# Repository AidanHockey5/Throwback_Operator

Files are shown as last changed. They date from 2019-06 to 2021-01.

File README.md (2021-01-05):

# THROWBACK OPERATOR
OPL3 VGM player powered by STM32

This project is a hardware video game music (VGM) player that uses a genuine YMF262 (OPL3) sound chip and its accompanying YAC512 DAC.
There is no emulation here. This is the real chip.

Included in this repository is the complete schematic, firmware source, and KiCAD board files. Feel free to make your own board, but please don't resell them :)

If you would like to purchase an official complete Throwback Operator board, you can order one from me here: https://www.aidanlawrence.com/product/throwback-operator/

# Information About the Main Sound Chips and VGM

The YMF262, also known as the Operator Type L3 (OPL3), is an 18-channel FM sound chip that was commonly found inside of personal computers in the mid to late 1990's.
Most notably, the OPL3 was found on the Sound Blaster Pro 2 and the Sound Blaster 16.
The OPL3 is backwards compatible with the OPL2 (YM3812). The OPL2 is backwards compatible with the original OPL (YM3526).
This means that the Throwback Operator is capable of playing back OPL3, OPL2, and OPL tracks. The OPL2 was found on the original Adlib and Sound Blaster cards.
The OPL was usually found within arcade machines.

The clock signal for the YMF262 is dynamically generated from the microcontroller. The timers on this particular board only have 16-bit resolution, so VGMs with exotic frequencies may not sound perfectly in tune. Standard clock OPL2 and OPL3 VGMs will often sound just fine though.

VGM stands for Video Game Music, and it is a 44.1KHz logging format that stores real sound chip register information. My player will parse these files and send the data to the appropriate chips. You can learn more about the VGM file format here: http://www.smspower.org/Music/VGMFileFormat

http://www.smspower.org/uploads/Music/vgmspec170.txt?sid=58da937e68300c059412b536d4db2ca0

# Schematic
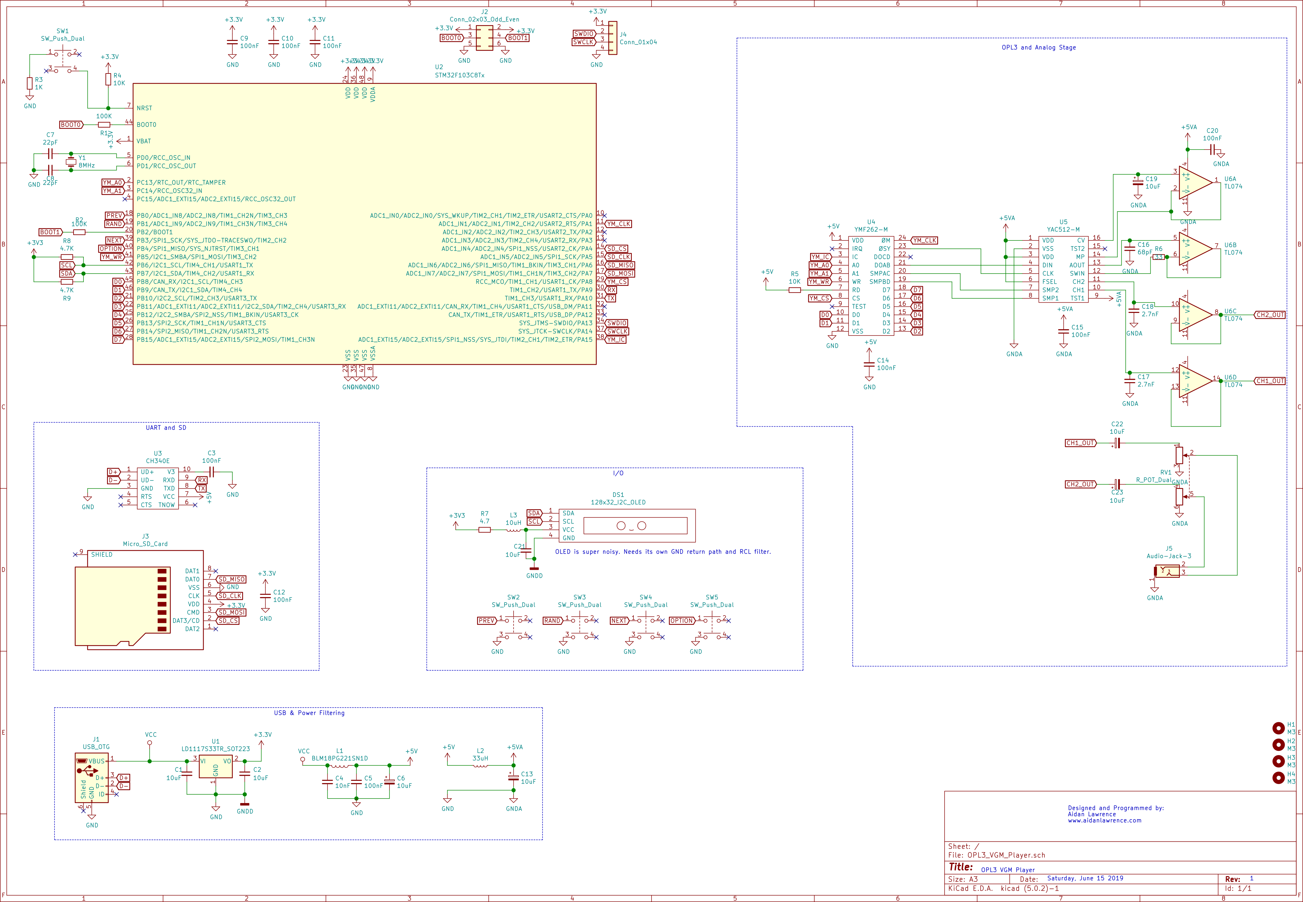
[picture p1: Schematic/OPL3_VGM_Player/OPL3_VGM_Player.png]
Schematic


# SD Card Information

The Throwback Operator accepts MicroSD cards formatted as FAT32. Your SD card must only contain uncompressed .vgm files. VGZ FILES WILL NOT WORK! You may download .vgz files and use 7zip to extract the uncompressed file out of them. Vgm files on the SD card do not need to have the .vgm extension. As long as they contain valid, uncompressed vgm data, they will be read by the program regardless of their name. You can find VGM files by Googling "myGameName VGM," or by checking out sites like http://vgmrips.net/packs/

# Control Over Serial
You can use a serial connection to control playback features. The commands are as follows:

Command | Result
------------ | -------------
\+ | Next Track
\- | Previous Track
\* | Random Track
\/ | Toggle Shuffle Mode
\. | Toggle Song Looping
r: | Request song
? | What song is playing?
\! | Toggle the OLED display

A song request is formatted as follows: ```r:mySongFile.vgm```
Once a song request is sent through the serial console, an attempt will be made to open that song file. The file must exist on the SD card, and spelling/capitalization must be correct.
Need an easy-to-use serial console? [I've made one here.](https://github.com/AidanHockey5/OpenArduinoSerialConsole)

# Programming the Microcontroller

The on-board microcontroller is a STM32F103C8T6, the same microcontroller found on the popular "blue pill" development boards. 
Therefore, programming the Throwback Operator boards is fairly similar.
The firmware was built with Visual Studio Code with the PlatformIO extension installed.

Programming over Serial:
* Connect your Throwback Operator board to your computers USB port.
* Ensure that you have the CH340 driver installed. Windows 10 should have this automatically, otherwise, [grab the driver here](https://sparks.gogo.co.nz/ch340.html)
* Ensure nothing else is currently connected to your board over serial.
* On the top of the board, you will see two black jumpers. By default, these jumpers are both in the "Down" position (middle pin and bottom pin jumped).
* Remove the left jumper and reattach it to the "Up" position (middle pin and top pin jumped).
* Press the RESET button on the Throwback Operator board

* You can either program the device with the flashing tool linked below, or from the source code.

[DOWNLOAD THE FLASHING TOOL HERE](https://www.aidanlawrence.com/tools/ee/tbo/Megaflasher_Throwback_Operator.zip)

* Windows users are reccomended to run the pre-compiled "Flash.exe" file.
  All other operating system users must run the Flash.py file. 
  Dependancies and instructions are listed in the Readme file.
* After successfully running the flashing tool, you are done and don't need to continue with the following instructions.

If you plan to build from the source code instead:
* In VS Code (or whatever your IDE of choice is), navigate to the `platformio.ini` and ensure the upload protocol is set to `serial`
* Hit the upload button (Arrow icon in the bottom bar of VS code)
* Once your code is uploaded, replace the left jumper to its original "Down" position 

# Troubleshooting

Occasionally, when the player is first plugged in, it will hang or get caught in a boot-loop. Plugging in a USB cable gives breif moments of unstable power when the contacts inside of the connector are jostling against eachother which may place the SD card in an unknown state. Simply disconnect and reconnect the USB cable if you are caught in a bootloop.

This player is for OPL-family VGMs only. That means you can play any VGM file that contains data for the YM3526 (OPL), YM3812 (OPL2) or the YMF262 (OPL3).

Ensure that your VGM files are uncompressed. VGZ files will not work. Simply use 7zip on VGM files to extract the VGM files within.

Make sure your SD card is formatted to FAT32 and only contains VGM files. Folders are not supported.

# Looking for an Enclosure for your Player?

Voodle has contributed a 3D-printable enclosure for the Throwback Operator!
https://www.thingiverse.com/thing:4577831

Thanks, Voodle!

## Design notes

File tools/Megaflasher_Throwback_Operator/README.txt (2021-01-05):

NO DEPENDANCIES OR PYTHON INSTALL REQUIRED FOR WINDOWS EXE

PYTHON DEPENDANCIES:
Python 3.0+
pyserial
requests

Enter the following commands:

pip install pyserial
pip install requests

Run:
python3 Flash.py

----------------------------------------------

Instructions for use:

On the THROWBACK OPERATOR DEVICE: Move the left jumper pin at the top of the board to the "UP" position.
It should look like this:
https://www.aidanlawrence.com/wp-content/uploads/2021/01/tbojumper-scaled.jpg

Plug-in your THROWBACK OPERATOR to your computer via USB.

Press the RESET BUTTON.

Run the Flash.exe program OR run Flash.py with Python.

Select the COM port of the THROWBACK OPERATOR.

If everything is correct, your system should automatically download the firmware file and flash.

After flashing, replace the jumper's position back to DOWN.

----------------------------------------------

EXE Built with pyinstaller
pyinstaller --onefile Flash.py

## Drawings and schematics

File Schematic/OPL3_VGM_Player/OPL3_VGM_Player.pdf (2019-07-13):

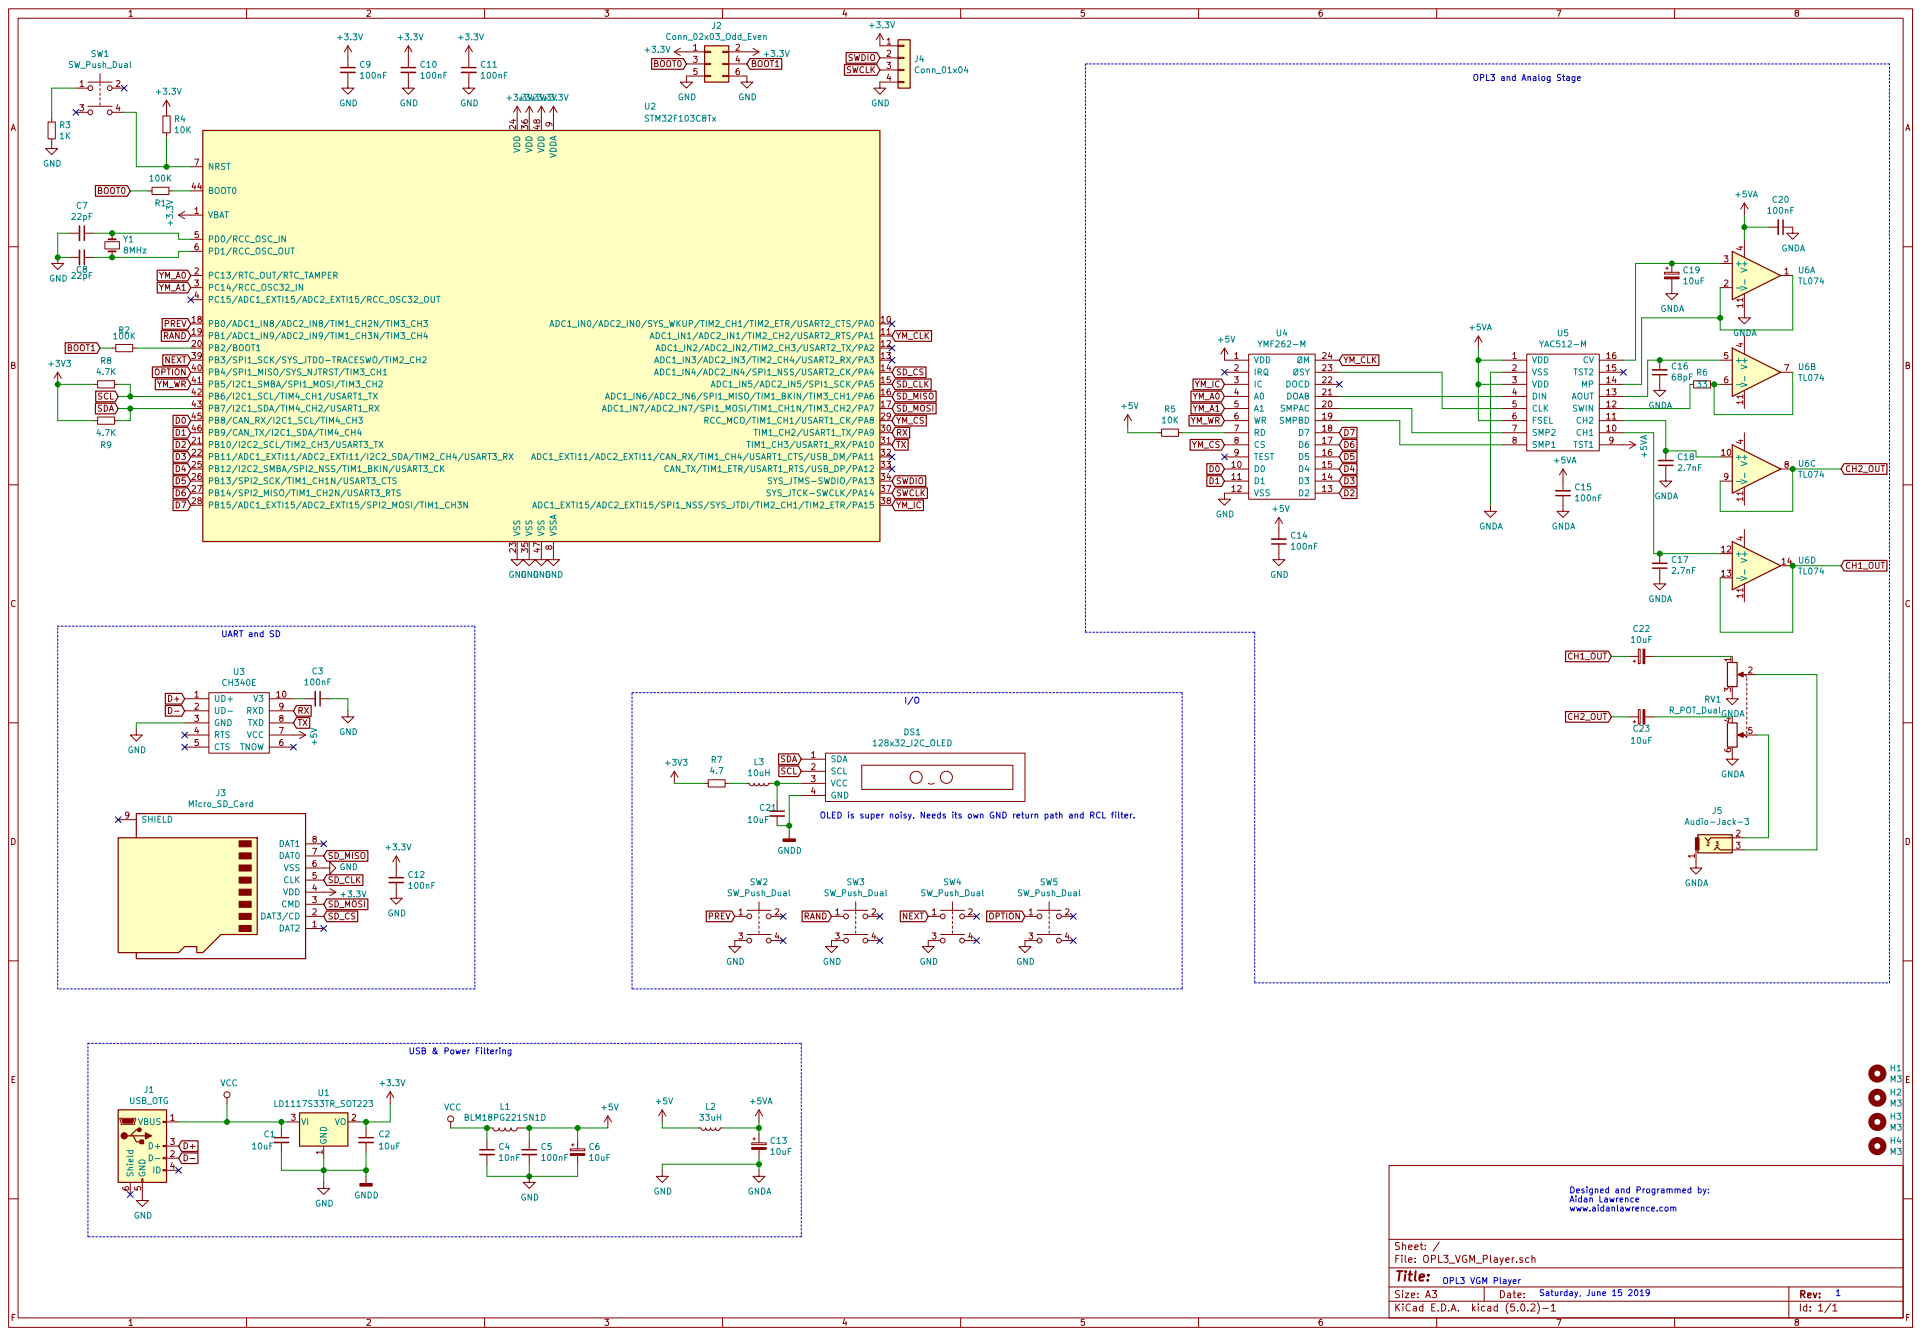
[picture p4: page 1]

9 VSS 23 VSS 35 VSS 47 VSSA

USB & Power Filtering UART and SD

Designed and Programmed by: Aidan Lawrence www.aidanlawrence.com

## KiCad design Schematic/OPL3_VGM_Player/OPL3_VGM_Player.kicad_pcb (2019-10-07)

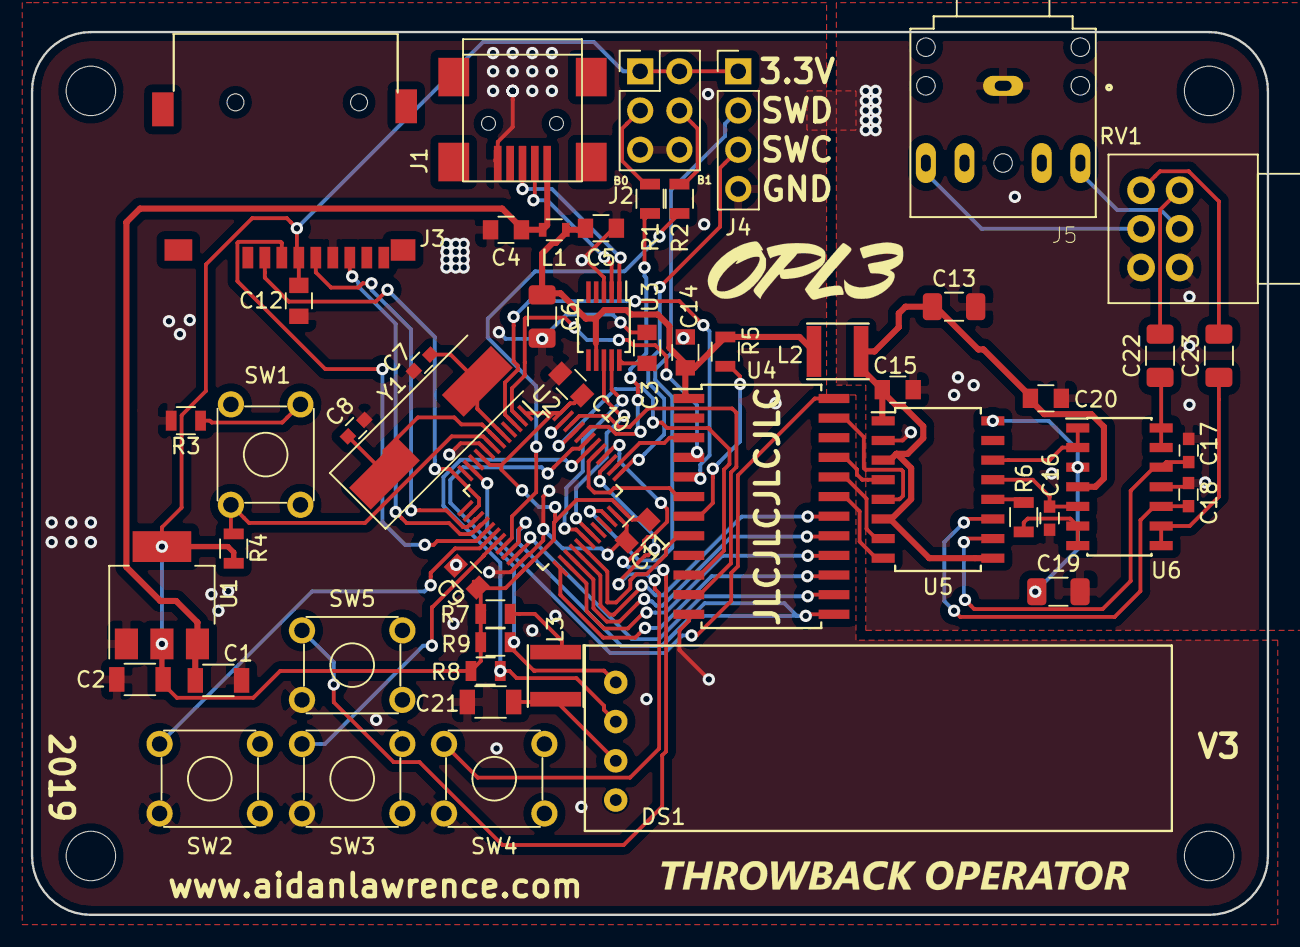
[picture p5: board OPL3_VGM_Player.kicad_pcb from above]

Board: 2 copper layers, 80.0 x 57.2 mm, 58 parts (0 on the bottom side), 64 nets.

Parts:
C1, C2, C21: 10uF; C_1206
C3, C5, C9, C10, C11, C12, C14, C15, C20: 100nF; C_0805
C4: 10nF; C_0805
C6, C13, C19, C22, C23: 10uF; C_1206_3216Metric
C7, C8: 22pF; C_0603
C16: 68pF; C_0603
C17, C18: 2.7nF; C_0603
DS1: 128x32_I2C_OLED; 128x32_OLED_I2C_Module
H1, H2, H3, H4: M3; MountingHole_3.2mm_M3
J1: USB_OTG; USB_Mini-B
J2: Conn_02x03_Odd_Even; Pin_Header_Straight_2x03_Pitch2.54mm
J3: Micro_SD_Card; SOFNG_TF_15x15_PUSH_PUSH
J4: Conn_01x04; Pin_Header_Straight_1x04_Pitch2.54mm
J5: Audio-Jack-3; Boom Precision Elec PJ-307C
L1: BLM18PG221SN1D; L_0603
L2: 33uH; L_4x4
L3: 10uH; L_4x4
R1, R2: 100K; R_0805
R3: 1K; R_0805
R4, R5: 10K; R_0805
R6: 33; R_0805
R7: 4.7; R_0805
R8, R9: 4.7K; R_0805
RV1: R_POT_Dual; Potentiometer_Alps_RK097_Double_Vertical
SW1, SW2, SW3, SW4, SW5: SW_Push_Dual; SW_TH_Tactile_Omron_B3F-10xx
U1: LD1117S33TR_SOT223; SOT-223-3_TabPin2
U2: STM32F103C8Tx; LQFP-48_7x7mm_Pitch0.5mm
U3: CH340E; MSOP-10_3x3mm_Pitch0.5mm
U4: YMF262-M; SOIC-24W_7.5x15.4mm_Pitch1.27mm
U5: YAC512-M; SOIC-16W_5.3x10.2mm_Pitch1.27mm
U6: TL074; SOIC-14_3.9x8.7mm_Pitch1.27mm
Y1: 8MHz; Crystal_SMD_HC49-SD

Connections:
+3V3: C2.1, C9.1, C10.1, C11.1, C12.1, J2.1, J2.2, J3.4, J4.1, R4.1, R7.2, R8.2, R9.2, U1.2, U2.1, U2.9, U2.24, U2.36, U2.48
+5V: C5.1, C6.1, C14.2, L1.1, L2.2, R5.2, U3.7, U4.1
+5VA: C13.1, C15.2, C20.2, L2.1, U5.1, U5.3, U5.6, U5.9, U6.4
BOOT0: J2.3, R1.2
BOOT1: J2.4, R2.2
CH1_OUT: C22.1, U6.13, U6.14
CH2_OUT: C23.1, U6.8, U6.9
D0: U2.45, U4.10
D1: U2.46, U4.11
D2: U2.21, U4.13
D3: U2.22, U4.14
D4: U2.25, U4.15
D5: U2.26, U4.16
D6: U2.27, U4.17
D7: U2.28, U4.18
D+: J1.3, U3.1
D-: J1.2, U3.2
GND: C1.2, C2.2, C3.1, C4.2, C5.2, C6.2, C7.2, C8.2, C9.2, C10.2, C11.2, C12.2, C13.2, C14.1, C15.1, C16.1, C17.1, C18.1, C19.2, C20.1, C21.2, DS1.4, J1.5, J2.5, J2.6, J3.6, J4.4, J5.1, R3.2, RV1.3, RV1.6, SW2.3, SW3.3, SW4.3, SW5.3, U1.1, U2.8, U2.23, U2.35, U2.47, U3.3, U4.12, U5.2
NEXT: SW4.1, U2.39
unnamed: C3.2, U3.10
unnamed: C7.1, U2.5, Y1.2
unnamed: C8.1, U2.6, Y1.1
unnamed: C16.2, U5.13, U6.5
unnamed: C17.2, U5.10, U6.12
unnamed: C18.2, U5.11, U6.10
unnamed: C19.1, U5.16, U6.3
unnamed: C21.1, DS1.3, L3.1
unnamed: C22.2, RV1.1
unnamed: C23.2, RV1.4
unnamed: J5.2, RV1.5
unnamed: J5.3, RV1.2
unnamed: L3.2, R7.1
unnamed: R1.1, U2.44
unnamed: R2.1, U2.20
unnamed: R3.1, SW1.1
unnamed: R4.2, SW1.4, U2.7
unnamed: R5.1, U4.7
unnamed: R6.1, U6.6, U6.7
unnamed: R6.2, U5.12
unnamed: U4.19, U5.8
unnamed: U4.20, U5.7
unnamed: U4.21, U5.4
unnamed: U4.23, U5.5
unnamed: U5.14, U6.1, U6.2
OPTION: SW5.1, U2.40
PREV: SW2.1, U2.18
RAND: SW3.1, U2.19
RX: U2.30, U3.9
SCL: DS1.2, R8.1, U2.42
SDA: DS1.1, R9.1, U2.43
SD_CLK: J3.5, U2.15
SD_CS: J3.2, U2.14
SD_MISO: J3.7, U2.16
SD_MOSI: J3.3, U2.17
SWCLK: J4.3, U2.37
SWDIO: J4.2, U2.34
TX: U2.31, U3.8
VCC: C1.1, C4.1, J1.1, L1.2, U1.3
YM_A0: U2.2, U4.4
YM_A1: U2.3, U4.5
YM_CLK: U2.11, U4.24
YM_CS: U2.29, U4.8
YM_IC: U2.38, U4.3
YM_WR: U2.41, U4.6

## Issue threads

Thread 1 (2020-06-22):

Timing/tempo issues on some VGMs

tomas, 2020-06-22:
I just tried listening to [this soundtrack](https://vgmrips.net/packs/pack/miwaku-no-chousho-pc-9801) from VGMRips, but unfortunately most of the songs seem to be "off" in terms of tempo or timing.

Is this what you refer to about "exotic frequencies" in the readme? Any way this can be fixed?

AidanHockey5, 2020-08-07:
Hello @tomas

Sorry for the late reply. I didn't see this issue!

So I've had issues with that specific VGM pack since day one. I'm not sure what's wrong with the Miwaku no Chousho pack, but I've always run into those same tempo issues on the first loop of some of the tracks. I've doubled-checked the starting addresses on the VGM parser pointer, and they're dead-on, so nothing is wrong with how the file is being parsed.
What's odd is that after the loop point, the track sounds fine, which suggests I might have a buffer issue, but I gave everything a look, and the values all seem to match the VGM file just fine.
There is a note on the VGM pack about "excessive vibrato" due to some conversion between OPN and OPL3, but I don't think that would be an issue. The OPL3 is simply executing the exact commands it receives from the VGM file, so I don't think I'm able to fix this, sadly. May just be a case of a bad VGM capture where software players don't have much of an issue with it, but the real hardware does. I could be wrong though, but since no other tracks behave like this, I'm lead to believe that it's a problem with the VGM files in that pack.

Fortunately, this seems to be the only VGM pack with an issue like this. If I'm missing something, I'd love to be proved wrong! It would be great to get this VGM pack working properly.

As for "exotic frequencies," that simply refers to OPL1/OPL2/OPL3 VGMs setting their chips to run at frequencies that aren't the standard colorburst derivatives. A little bit of math is required to compensate for unusual chip clock speeds, and since the STM32 on-board only has a 16-bit timer, sometimes the resulting clock outputs aren't precisely what the VGM calls for, as the timer resolution is too low. TL;DR, not the issue you're running into :P

AidanHockey5, 2021-01-31:
Finally fixed with the latest firmware's new VGM engine!
https://github.com/AidanHockey5/Throwback_Operator/releases/tag/2.0

#2

Closed 2021-01-31.

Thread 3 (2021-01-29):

Tl074 is marginal at 5V

prosper00, 2021-01-29:
I built up your circuit out of parts i had on hand, and found it to be quite sensitive to voltage fluctuations. I narrowed the problems down to the analog side of the circuit, and eventually to the tl074 acting 'weird'. I had incorporated a chip amp on my board, and it was pulling the voltage down just enough to cause the opamp to lock up. Raising the input voltage from 4.9v on usb to 5.2v improves things somewhat, but, looking at the datasheet for the '074, it seems like its still running right near the edge of its range.

I cant think of a quad op amp off the top of my head that might work better - i have some lf347' s on hand, which are SLIGHTLY improved versions of the tl074, and I'm going to play around with maybe using a pair of dual amps.

AidanHockey5, 2021-01-31:
Sensitive to voltage fluctuations? Could you elaborate a bit more, please?

Any chance you could drop an audio sample so I can take a listen to what you're experiencing? You might have a floating pin on your DAC or amp somewhere.

This device expects 5V on USB.

>I had incorporated a chip amp on my board

Please show your circuit

prosper00, 2021-01-31:
Sure, its your circuit, with a tda2822m on board, according to its datasheet... I'll draw something up in kicad. The only changes i made other than that were to add a 1000uf, 10uf an 100nf decoupling capacitors in parallel right where the power comes in to the board. Running off a usb port on my computer, i measure 4.9V.  The tda2822 can pull almost an amp, which pulls the voltage down as low as 4.3V, which is certainly my problem. Soundwise, it sounds like really severe clipping, especially on percussion parts.

Anyway, with a better power supply, larger gauge wires, and a bigger power connector (5.5mm barrel jack instead of microusb) , the problems go away.

AidanHockey5, 2021-01-31:
Oh, wow, yeah. This circuit was designed to provide line-level output. Placing a power amp of that size would drive your voltage down for sure. USB power is totally not recommended for those amps at those kinds of power levels. Just so you know, it’s not a good idea to put 1000uF across USB powered devices. Officially, you’re supposed to limit yourself to 10uF max, but a little extra capacitance has a pretty negligible effect. 1000uF is enough to momentarily sag the voltage enough to disrupt other USB devices.

An external power supply is indeed recommended for your changes.

Since this device was originally designed to be line-level out, it probably would be a better idea to use an external amplifier, powered speakers, or your computers line-in instead of adding a power amp to the design.

prosper00, 2021-07-05:
FWIW - I tinkered with this on and off for a few months, never really getting it to sound great. Changed out op-amps, added a really overkill linear power supply, swapped out my 'CKS32' knockoff board for a real STM32, re-wired everything several times... I kept getting an intermittent clipping problem. Sometimes it would sound great, other times it sounded really distorted, like it was clipping. Really frustrating. And it really seemed like a voltage issue, too - 'bumping' the voltage around on my bench power supply sometimes cleared things up

Poking around with my 'scope and looking at the datasheets, I think I finally found the issue - I have apparently a bad batch of YAC512 DAC's. At least two of them straight up fail to provide any analog output at all, and one sorta works, but the output level is all over the place. Turns out that these chips have a built-in voltage reference which is buffered by the opamp and then fed back into the analog side of the DAC, which ends up providing a centering voltage for the output. (pins 14 and 16). Mine was providing an output voltage of about 0.8V, (and it should be 1/2 VCC, or 2.5V). This was centering the analog around the 0.8V mark, which accounts for my clipping and distortion. Anyway, I provided my own 2.5V ref to the DAC pin 14, and everything works great now, including the power amplifier. I have a speaker onboard and everything.

Now I gotta find a source for some non-defective DAC's.

Closed 2021-01-31.

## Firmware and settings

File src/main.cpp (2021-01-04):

#include <Arduino.h>
#include <libmaple/iwdg.h>
#include <SPI.h>
#include "SdFat.h"
#include <U8g2lib.h>
#include "TrackStructs.h"
#include "SerialUtils.h"
#include "VGMEngine.h"

//Debug variables
//REMOVE IN PCB VERSION
#define ENABLE_DEBUG_PORT_PIN PB3 //If this pin is HIGH, enable the debug port pins, otherwise, disable the pins. Keep pin low by default. Disables STlink when low.
//REMOVE IN PCB VERSION
#define DEBUG false //Set this to true for a detailed printout of the header data & any errored command bytes
#define DEBUG_LED PC15

//Prototypes
void setup();
void loop();
//void setClock(uint32_t frq);
void handleSerialIn();
void tick();
void removeMeta();
void handleButtons();
void startISR();
void pauseISR();
void drawOLEDTrackInfo();
bool startTrack(FileStrategy fileStrategy, String request = "");

//Sound Chip
OPL3 opl3; //Pins are already self-contained in this driver class.

//SD & File Streaming
SdFat SD;
File file;
#define MAX_FILE_NAME_SIZE 128
char fileName[MAX_FILE_NAME_SIZE];
uint32_t numberOfFiles = 0;
uint32_t currentFileNumber = 0;

//Counters
uint32_t bufferPos = 0;
uint32_t cmdPos = 0;
uint16_t waitSamples = 0;

//VGM Variables
uint16_t loopCount = 0;
const uint8_t maxLoops = 3;
bool fetching = false;
bool trackError = false;
//PlayMode playMode = PlayMode::IN_ORDER;

//IO
const uint8_t next_btn = PB3;
const uint8_t prev_btn = PB0;
const uint8_t rand_btn = PB1;
const uint8_t option_btn = PB4;

//OLED
U8G2_SSD1306_128X32_UNIVISION_F_SW_I2C u8g2(U8G2_R0, PB6, PB7, U8X8_PIN_NONE); //SW I2C for now, HW seems to have a bug that crashes the unit
bool isOledOn = true;

void setup()
{
  //init watchdog timer to reset on crash
  //iwdg_init(IWDG_PRE_32, INT16_MAX);

  //For breadboard prototypes only.
  //Use ENABLE_DEBUG_PORT_PIN as a jumper to enable and disable the SWD pins
  //pinMode(ENABLE_DEBUG_PORT_PIN, INPUT);
  //digitalRead(ENABLE_DEBUG_PORT_PIN) ? enableDebugPorts() : disableDebugPorts();


  //DISABLE DEBUG BY DEFAULT IN PCB VERSION!!!
  disableDebugPorts();

  //Output OPL3 clock on PA1
  /****configure clocks for PORTA & TIMER2********/
  RCC_BASE->APB2ENR |= RCC_APB2ENR_IOPAEN; // enable port A clock
  RCC_BASE->APB1ENR |= RCC_APB1ENR_TIM2EN; // enable clock for timer 2

  /* Porta Pin 1 &2 as alternate function output Push pull */
  GPIOA->regs->CRL = 0x000000BB;  
  /* Output Compare Mode, ENABLE Preload,PWM  mode:2*/
  TIMER2_BASE->CCMR1 = 0x00007800;
  TIMER2_BASE->EGR |= 0x00000001;     // ENABLE update generation
  /*CC2E : channel 2 enabled; polarity : active high*/      
  TIMER2_BASE->CCER = 0x00000010; 
  TIMER2_BASE->CR1 |= 0x00000080;     // Auto preload ENABLE
  TIMER2_BASE->CR1 |= 0x00000001;     // ENABLE Timer counter  
  TIMER2_BASE->CCR2 = 2;              // SET duty cycle to 50%

  setClock(OPL_DEFAULT_CLOCK);
  
  //Set Chips
  VGMEngine.opl3 = &opl3;

  playMode = PlayMode::SHUFFLE;

  delay(100);

  u8g2.begin();
  u8g2.setFont(u8g2_font_fub11_tf);
  u8g2.clearBuffer();
  u8g2.drawStr(0,16,"Aidan Lawrence");
  u8g2.drawStr(0,32,"OPL3, 2019");
  u8g2.sendBuffer();

  delay(250);

  //DEBUG
  pinMode(DEBUG_LED, OUTPUT);
  digitalWrite(DEBUG_LED, LOW);

  //COM
  Serial.begin(9600);

  //IO
  pinMode(next_btn, INPUT_PULLUP);
  pinMode(prev_btn, INPUT_PULLUP);
  pinMode(rand_btn, INPUT_PULLUP);
  pinMode(option_btn, INPUT_PULLUP);

  //SD
  while(!SD.begin(PA4, SPI_HALF_SPEED)) 
  {
    SD.begin(PA4, SPI_HALF_SPEED);
    delay(100);
    u8g2.clearBuffer();
    u8g2.drawStr(0,16,"SD Mount");
    u8g2.drawStr(0,32,"failed!");
    u8g2.sendBuffer();
    Serial.println("SD MOUNT FAILED");
  }

  //Prepare files
  removeMeta();

  File countFile;
  while ( countFile.openNext( SD.vwd(), O_READ ))
  {
    countFile.close();
    countFile.getName(fileName, MAX_FILE_NAME_SIZE);
    
    numberOfFiles++;
  }
  countFile.close();
  SD.vwd()->rewind();

  //Begin
  startTrack(FIRST_START);
}

void pauseISR()
{
  Timer4.pause();
  Timer4.refresh();
}

void setISR()
{
  Timer4.pause();
  Timer4.setPrescaleFactor(1);
  Timer4.setOverflow(1633);
  Timer4.setChannel1Mode(TIMER_OUTPUT_COMPARE);
  Timer4.attachCompare1Interrupt(tick);
  Timer4.refresh();
  Timer4.resume();  
}

void drawOLEDTrackInfo()
{
  if(isOledOn)
  {
    u8g2.setPowerSave(0);
    u8g2.setFont(u8g2_font_helvR08_tf);
    u8g2.clearBuffer();
    u8g2.drawStr(0,9, widetochar(VGMEngine.gd3.enTrackName));
    u8g2.drawStr(0,22, widetochar(VGMEngine.gd3.enGameName));

    u8g2.setFont(u8g2_font_micro_tr);
    if(playMode == PlayMode::LOOP)
      u8g2.drawStr(0,32, "LOOP");
    else if(playMode == PlayMode::SHUFFLE)
      u8g2.drawStr(0,32, "SHUFFLE");
    else
      u8g2.drawStr(0,32, "IN ORDER");
  }
  else
  {
    u8g2.clearDisplay();
    u8g2.setPowerSave(1);
  }
  u8g2.sendBuffer();
}

//Mount file and prepare for playback. Returns true if file is found.
bool startTrack(FileStrategy fileStrategy, String request)
{
  pauseISR();
  File nextFile;
  memset(fileName, 0x00, MAX_FILE_NAME_SIZE);

  switch(fileStrategy)
  {
    case FIRST_START:
    {
      nextFile.openNext(SD.vwd(), O_READ);
      nextFile.getName(fileName, MAX_FILE_NAME_SIZE);
      nextFile.close();
      currentFileNumber = 0;
    }
    break;
    case NEXT:
    {
      if(currentFileNumber+1 >= numberOfFiles)
      {
          SD.vwd()->rewind();
          currentFileNumber = 0;
      }
      else
          currentFileNumber++;
      nextFile.openNext(SD.vwd(), O_READ);
      nextFile.getName(fileName, MAX_FILE_NAME_SIZE);
      nextFile.close();
    }
    break;
    case PREV:
    {
      if(currentFileNumber != 0)
      {
        currentFileNumber--;
        SD.vwd()->rewind();
        for(uint32_t i = 0; i<=currentFileNumber; i++)
        {
          nextFile.close();
          nextFile.openNext(SD.vwd(), O_READ);
        }
        nextFile.getName(fileName, MAX_FILE_NAME_SIZE);
        nextFile.close();
      }
      else
      {
        currentFileNumber = numberOfFiles-1;
        SD.vwd()->rewind();
        for(uint32_t i = 0; i<=currentFileNumber; i++)
        {
          nextFile.close();
          nextFile.openNext(SD.vwd(), O_READ);
        }
        nextFile.getName(fileName, MAX_FILE_NAME_SIZE);
        nextFile.close();
      }
    }
    break;
    case RND:
    {
      randomSeed(micros());
      uint32_t randomFile = currentFileNumber;
      if(numberOfFiles > 1)
      {
        while(randomFile == currentFileNumber)
          randomFile = random(numberOfFiles-1);
      }
      currentFileNumber = randomFile;
      SD.vwd()->rewind();
      nextFile.openNext(SD.vwd(), O_READ);
      {
        for(uint32_t i = 0; i<randomFile; i++)
        {
          nextFile.close();
          nextFile.openNext(SD.vwd(), O_READ);
        }
      }
      nextFile.getName(fileName, MAX_FILE_NAME_SIZE);
      nextFile.close();
    }
    break;
    case REQUEST:
    {
      request.trim();
      char *cstr = &request[0u]; //Convert to C-string
      if(SD.exists(cstr))
      {
        file.close();
        strcpy(fileName, cstr);
        Serial.println("File found!");
      }
      else
      {
        Serial.println("ERROR: File not found! Continuing with current song.");
        goto fail;
      }
    }
    break;
  }

  if(SD.exists(fileName))
    file.close();
  file = SD.open(fileName, FILE_READ);
  if(!file)
  {
    Serial.println("Failed to read file");
    goto fail;
  }
  else
  {
    delay(100);
    if(VGMEngine.begin(&file))
    {
      printlnw(VGMEngine.gd3.enGameName);
      printlnw(VGMEngine.gd3.enTrackName);
      printlnw(VGMEngine.gd3.enSystemName);
      printlnw(VGMEngine.gd3.releaseDate);
      drawOLEDTrackInfo();
      setISR();
      return true;
    }
    else
    {
      Serial.println("Header Verify Fail");
      goto fail;
    }
  }

  fail:
  trackError = true;
  setISR();
  return false;
}

void removeMeta() //Sometimes, Windows likes to place invisible files in our SD card without asking... GTFO!
{
  File tmpFile;
  while ( tmpFile.openNext( SD.vwd(), O_READ ))
  {
    memset(fileName, 0x00, MAX_FILE_NAME_SIZE);
    tmpFile.getName(fileName, MAX_FILE_NAME_SIZE);
    if(fileName[0]=='.')
    {
      if(!SD.remove(fileName))
      if(!tmpFile.rmRfStar())
      {
        Serial.print("FAILED TO DELETE META FILE"); Serial.println(fileName);
      }
    }
    if(String(fileName) == "System Volume Information")
    {
      if(!tmpFile.rmRfStar())
        Serial.println("FAILED TO REMOVE SVI");
    }
    tmpFile.close();
  }
  tmpFile.close();
  SD.vwd()->rewind();
}

//Count at 44.1KHz
void tick()
{
  VGMEngine.tick();
}

//Poll the serial port
void handleSerialIn()
{
  while(Serial.available())
  {
    pauseISR();
    char serialCmd = Serial.read();
    switch(serialCmd)
    {
      case '+':
        startTrack(NEXT);
      break;
      case '-':
        startTrack(PREV);
      break;
      case '*':
        startTrack(RND);
      break;
      case '/':
        playMode = SHUFFLE;
        drawOLEDTrackInfo();
      break;
      case '.':
        playMode = LOOP;
        drawOLEDTrackInfo();
      break;
      case '?':
        printlnw(VGMEngine.gd3.enGameName);
        printlnw(VGMEngine.gd3.enTrackName);
        printlnw(VGMEngine.gd3.enSystemName);
        printlnw(VGMEngine.gd3.releaseDate);
      break;
      case '!':
        isOledOn = !isOledOn;
        drawOLEDTrackInfo();
      break;
      case 'r':
      {
        String req = Serial.readString();
        req.remove(0, 1); //Remove colon character
        startTrack(REQUEST, req);
      }
      break;
      default:
        continue;
    }
  }
  Serial.flush();
  setISR();
}

//Check for button input
bool buttonLock = false;
void handleButtons()
{
  bool togglePlaymode = false;
  uint32_t count = 0;
  
  if(!digitalRead(next_btn))
    startTrack(NEXT);
  if(!digitalRead(prev_btn))
    startTrack(PREV);
  if(!digitalRead(rand_btn))
    startTrack(RND);
  if(!digitalRead(option_btn))
    togglePlaymode = true;
  else
    buttonLock = false;
  while(!digitalRead(option_btn))
  {
    pauseISR();
    if(count >= 100) 
    {
      //toggle OLED after one second of holding OPTION button
      isOledOn = !isOledOn;
      drawOLEDTrackInfo();
      togglePlaymode = false;
      buttonLock = true;
      break;
    } 
    delay(10);
    count++;
  }
  if(buttonLock)
  {
    togglePlaymode = false;
    setISR();
  }

  if(togglePlaymode)
  {
    togglePlaymode = false;
    if(playMode == PlayMode::SHUFFLE)
      playMode = PlayMode::LOOP;
    else if(playMode == PlayMode::LOOP)
      playMode = PlayMode::IN_ORDER;
    else if(playMode == PlayMode::IN_ORDER)
      playMode = PlayMode::SHUFFLE;
    drawOLEDTrackInfo();
    setISR();
  }
}

void loop()
{   
  if(trackError)
  {
    startTrack(NEXT);
    trackError = false;
  }
  while(!VGMEngine.play()) //needs to account for LOOP playmode
  {
    if(Serial.available() > 0)
      handleSerialIn();
    handleButtons();
    if(trackError)
    {
      startTrack(NEXT);
      trackError = false;
    }
  }
  //Hit max loops and/or VGM exited
  if(playMode == PlayMode::SHUFFLE)
    startTrack(RND);
  if(playMode == PlayMode::IN_ORDER)
    startTrack(NEXT);
  //iwdg_feed();
}

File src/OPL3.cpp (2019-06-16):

#include "OPL3.h"

union U_32
{
    uint32_t fullWord;
    uint8_t bytes[4]; //0-1 LOW+HIGH, 2-3 EMPTY
} port;

void Write(uint8_t data)
{
    port.fullWord = GPIOB->regs->ODR; //Grab current state of the port
    port.bytes[1] = data;       //Stuff data byte into section where the 8-bit GPIO data bus is
    GPIOB->regs->ODR = port.fullWord; //Send it back to the port
}

void OPL3::Send(uint8_t addr, uint8_t data, bool setA1)
{
    GPIOC->regs->BSRR = (1U << 14) << (16 * !setA1);    //A1 setA1
    GPIOC->regs->ODR &= ~(0x2000);                      //A0 LOW
    Write(addr);
    GPIOB->regs->ODR &= ~(0x20);                        //WR LOW
    GPIOA->regs->ODR |= 0x100;                          //CS LOW (OPEN_DRAIN : HIGH)
    delayMicroseconds(2);
    GPIOB->regs->ODR |= 0x20;                           //WR HIGH
    GPIOA->regs->ODR &= ~(0x100);                       //CS HIGH (OPEN_DRAIN : LOW)
    GPIOC->regs->ODR |= 0x2000;                         //A0 HIGH
    Write(data);
    GPIOB->regs->ODR &= ~(0x20);                        //WR LOW
    GPIOA->regs->ODR |= 0x100;                          //CS LOW (OPEN_DRAIN : HIGH)
    delayMicroseconds(2);
    GPIOB->regs->ODR |= 0x20;                           //WR HIGH
    GPIOA->regs->ODR &= ~(0x100);                       //CS HIGH (OPEN_DRAIN : LOW)
}

 void OPL3::SetOPLMode(bool isOPL3)
 {
    Reset();
    Send(0x05, isOPL3, 1); //Set the OPL mode. Write 1 to this address for OPL3, 0 for OPL2.
    delayMicroseconds(5);
 }

void OPL3::Reset()
{
    digitalWrite(IC, LOW);
    delayMicroseconds(100);
    digitalWrite(IC, HIGH);
    delayMicroseconds(100);
}

OPL3::OPL3()
{
    pinMode(IC, OUTPUT_OPEN_DRAIN);
    pinMode(CS, OUTPUT_OPEN_DRAIN);
    pinMode(A0, OUTPUT);
    pinMode(A1, OUTPUT);
    pinMode(WR, OUTPUT);

    digitalWrite(IC, HIGH);
    digitalWrite(CS, HIGH);
    digitalWrite(A0, HIGH);
    digitalWrite(A1, HIGH);
    digitalWrite(WR, HIGH);

    pinMode(PB8, OUTPUT);
    pinMode(PB9, OUTPUT);
    pinMode(PB10, OUTPUT);
    pinMode(PB11, OUTPUT);
    pinMode(PB12, OUTPUT);
    pinMode(PB13, OUTPUT);
    pinMode(PB14, OUTPUT);
    pinMode(PB15, OUTPUT);
}

OPL3::~OPL3()
{
}

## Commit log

2019-05-10 Made some timers, chip drivers, you know, that kinda thing
2019-05-12 Driver now outputs OPL2/3 music.
2019-05-13 Minor OPL2/3 switch fix
    [OPL3.cpp]
2019-05-29 UART serial instead of native USB. Add OLED
2019-06-16 Begin schematic
    [OPL3_VGM_Player.kicad_pcb, OPL3_VGM_Player.sch]
2019-06-16 Saving work on schematic. IO Pin Changes
    [OPL3_VGM_Player.sch]
2019-06-17 Schematic plotted
    [OPL3_VGM_Player.sch]
2019-06-18 PCB first pass
    [OPL3_VGM_Player.kicad_pcb, OPL3_VGM_Player.sch]
2019-06-19 PCB Complete
    [OPL3_VGM_Player-B.Cu.gbr, OPL3_VGM_Player-B.Mask.gbr, OPL3_VGM_Player-B.Paste.gbr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]
2019-06-25 Modify firmware for PCB
2019-07-13 Added schematic images and pdf
2019-08-29 Minor change to headphone jack
    [OPL3_VGM_Player-B.Cu.gbr, OPL3_VGM_Player-B.Mask.gbr, OPL3_VGM_Player-B.Paste.gbr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]
2019-10-07 SMD caps and fixed headphone jack pin sizes
    [OPL3_VGM_Player-B.Cu.gbr, OPL3_VGM_Player-B.Paste.gbr, OPL3_VGM_Player-B_Cu.gbr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]
